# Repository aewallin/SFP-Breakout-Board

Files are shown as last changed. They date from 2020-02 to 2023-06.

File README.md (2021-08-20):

# SFP-Breakout-Board
SFP fibre-optical transciever simple breakout board. Works up to at least 1 Gbit/s.

* differential TX+/TX- RX+/RX- outputs/inputs with SMA connectors
* connector and cage for SFP or SFP+ transciever
* +3V3 power for transciever
* Three status LEDs for TX_FAULT, LOS, and MOD_ABS
* jumpers for SFP rate-select settings.

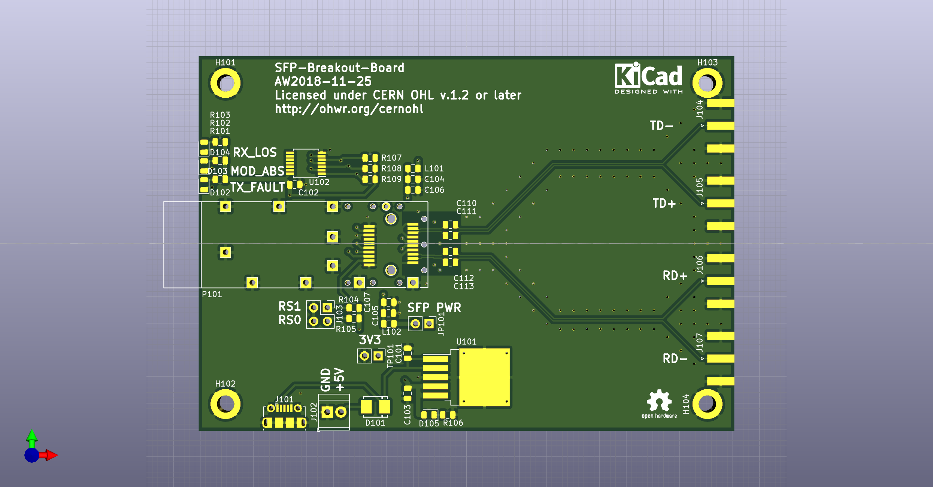
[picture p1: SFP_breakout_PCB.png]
PCB PCB image


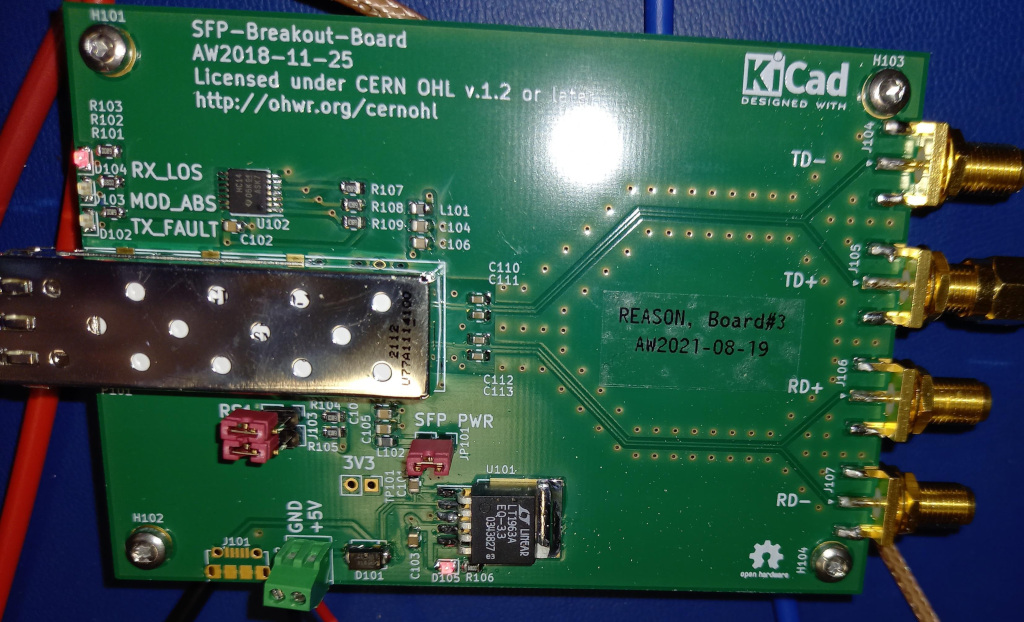
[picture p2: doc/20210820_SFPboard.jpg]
Board PCB image 2


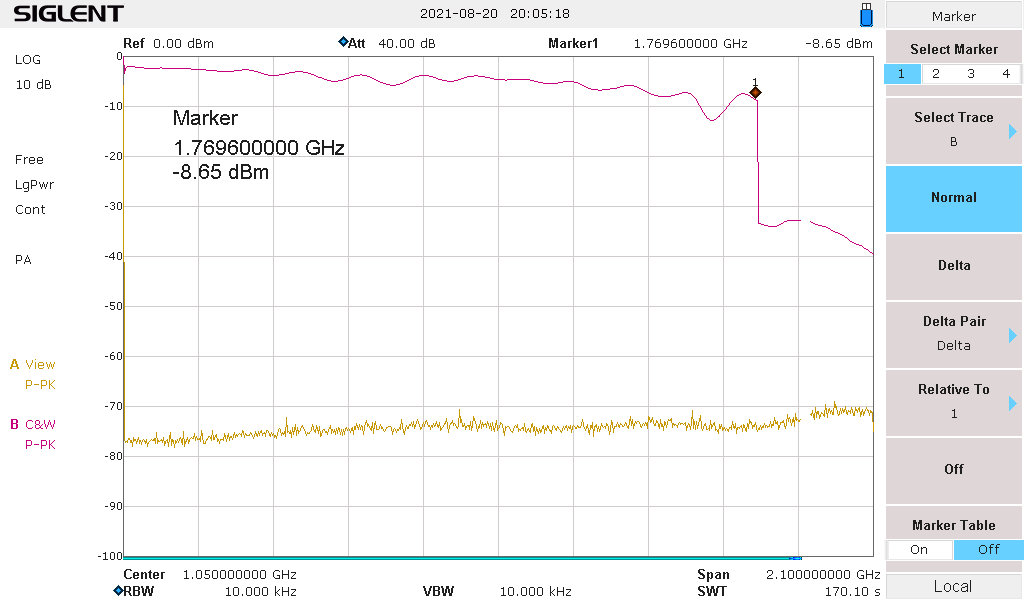
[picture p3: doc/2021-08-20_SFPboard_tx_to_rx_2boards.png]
SA Spectrum analyzer


Spectrum analyzer measurement of tracking-generator output to Tx-board with SFP, short 2 m fiber, and RX-output of receiving board with SFP. Bandwidth up to ca 1.8 GHz.

See also these other similar projects:

* https://github.com/aewallin/SFP2SMA_2018.03  single-ended input/output, with op-amp and transformer coupling to SFP
* https://osmocom.org/projects/misc-hardware/wiki/Sfp-experimenter
* https://osmocom.org/projects/misc-hardware/wiki/Sfp-breakout
* Multi-SFP crate https://www.ohwr.org/project/sfp-plus-i2c/wikis/home

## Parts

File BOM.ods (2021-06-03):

 | https://github.com/aewallin/SFP-Breakout-Board
 | Bill Of Materials
REF | Description | Qty | Price | Total | Farnell no | Digikey no | mfg part nr.
P101 | SFP connector | 1 |  |  | 1654067 | A97943CT-ND | 1888247-1
 | SFP Cage | 1 |  |  | 1849934 | U77-A1114-100TCT-ND | U77-A1114-100T
J104,105,106,107 | SMA connector | 4 | 5.25 |  |  | ACX1426-ND | 132289
U102 | 74HC14, TSSOP-14 | 1 |  |  |  | 296-8234-1-ND | SN74HC14PWR
D102, D103, D104 | SMD 0805 LED | 3
U101 | LT1963AEQ-3.3 | 1 |  |  |  | LT1963AEQ-3.3#TRPBFCT-ND | LT1963AEQ-3.3#TRPBF
J102 | 2-pin screw terminal | 1 |  |  |  | A98333-ND | 282834-2
L | SMD 0805 inductor
 | PCB, 2-sided, 90x70 mm | 10 | 12.5 | 125

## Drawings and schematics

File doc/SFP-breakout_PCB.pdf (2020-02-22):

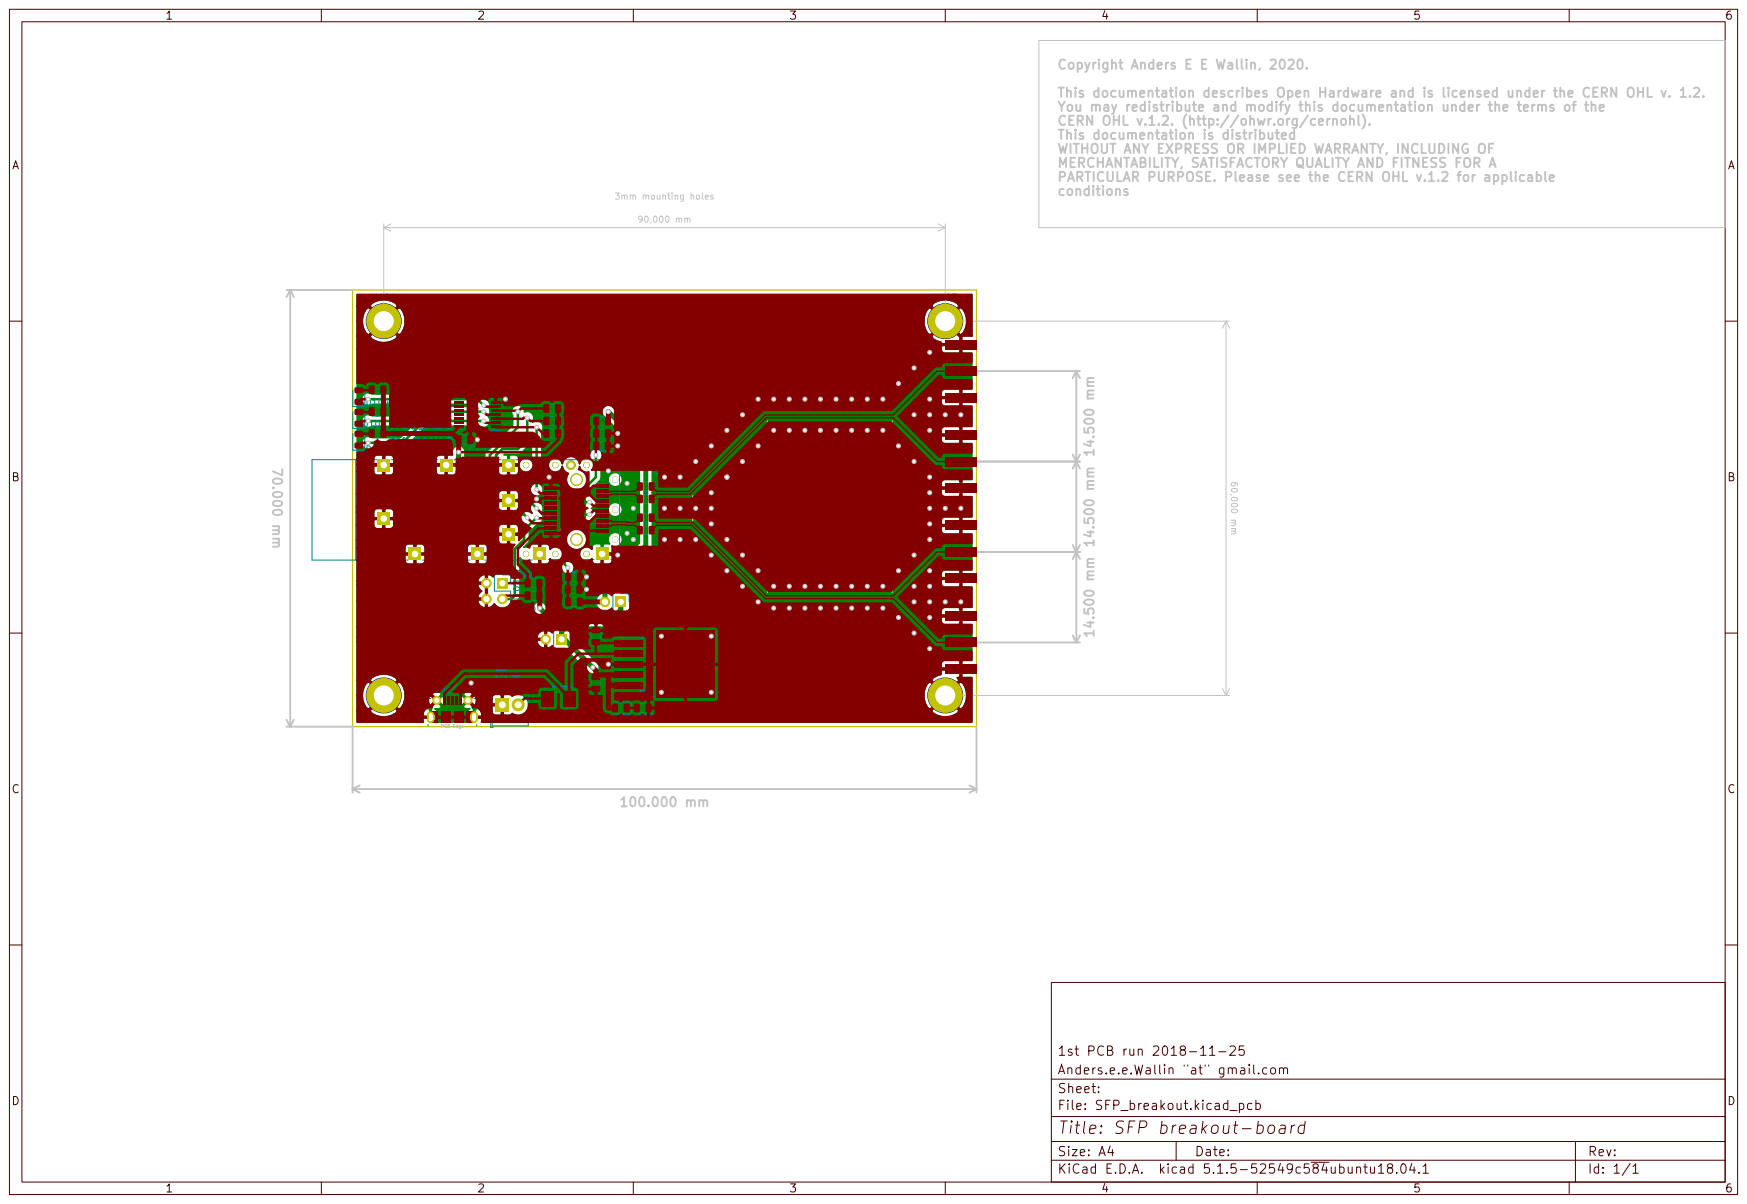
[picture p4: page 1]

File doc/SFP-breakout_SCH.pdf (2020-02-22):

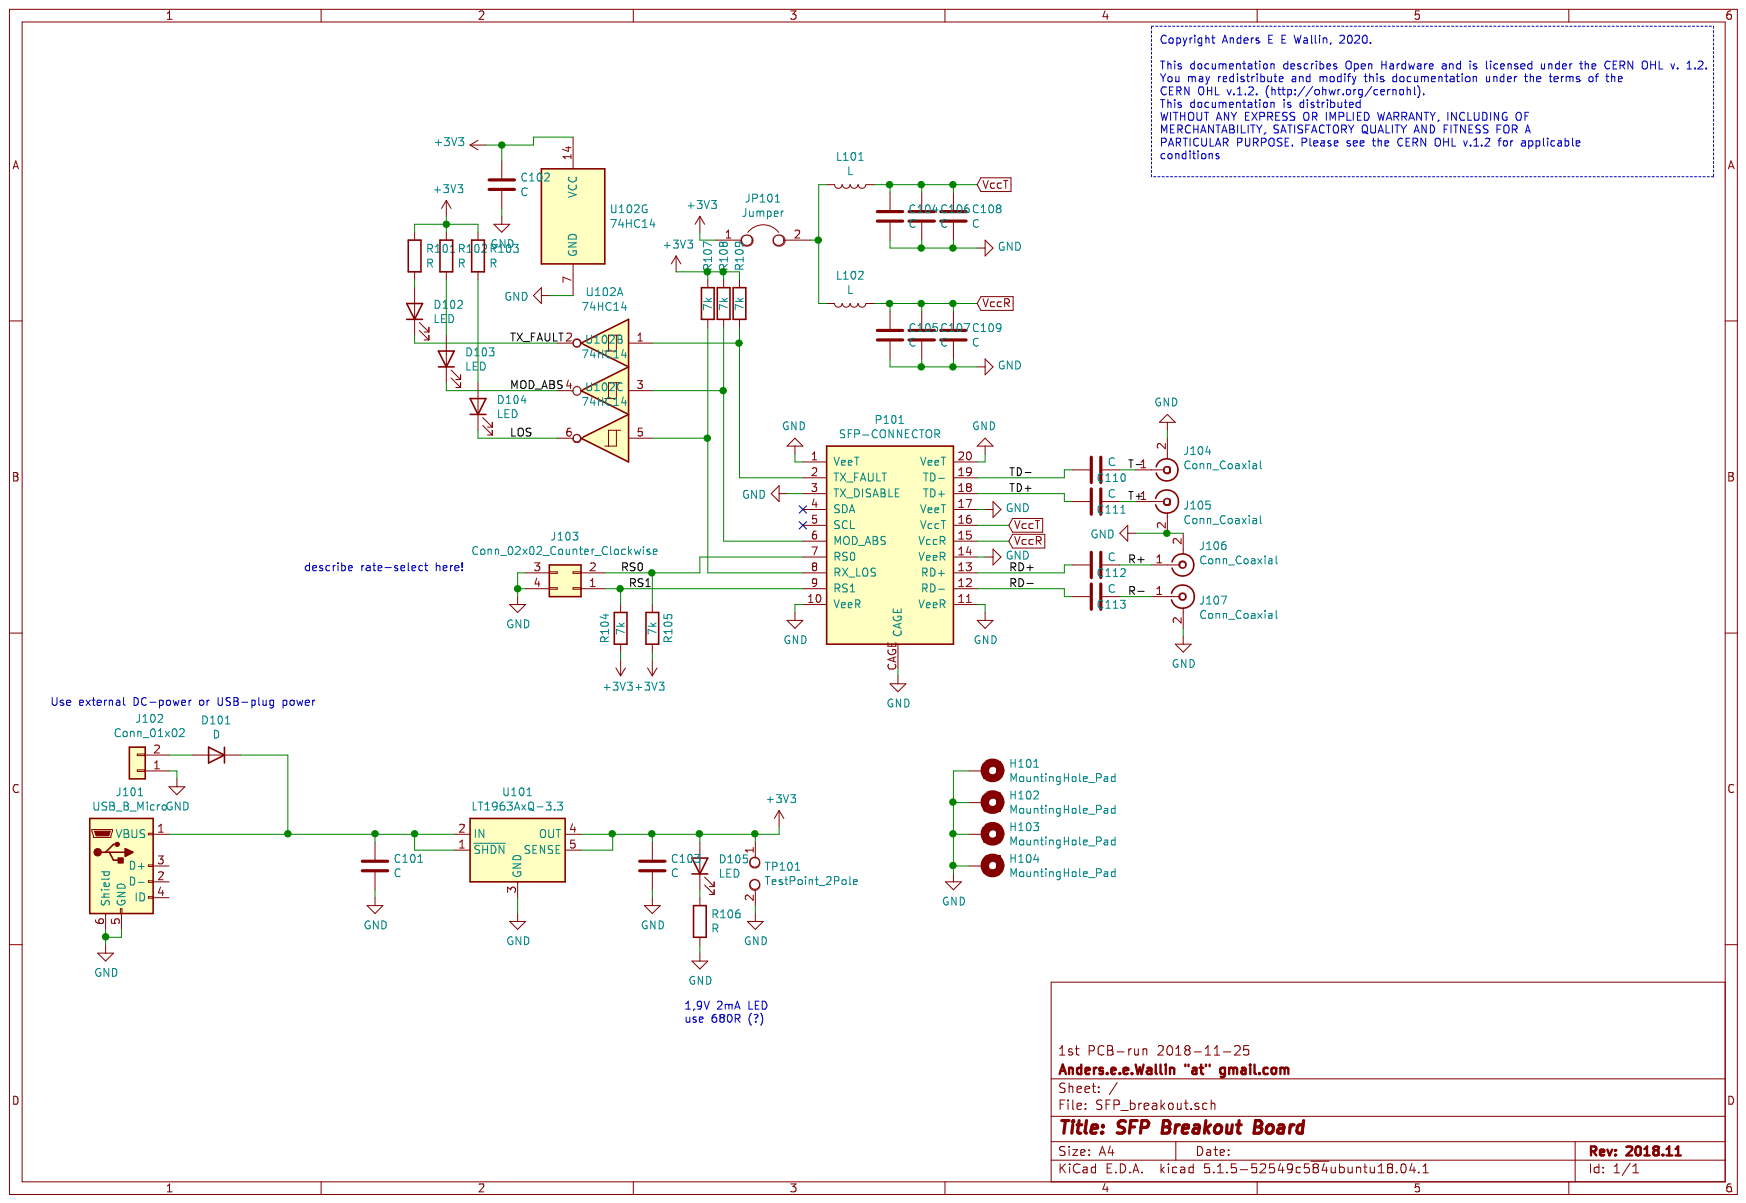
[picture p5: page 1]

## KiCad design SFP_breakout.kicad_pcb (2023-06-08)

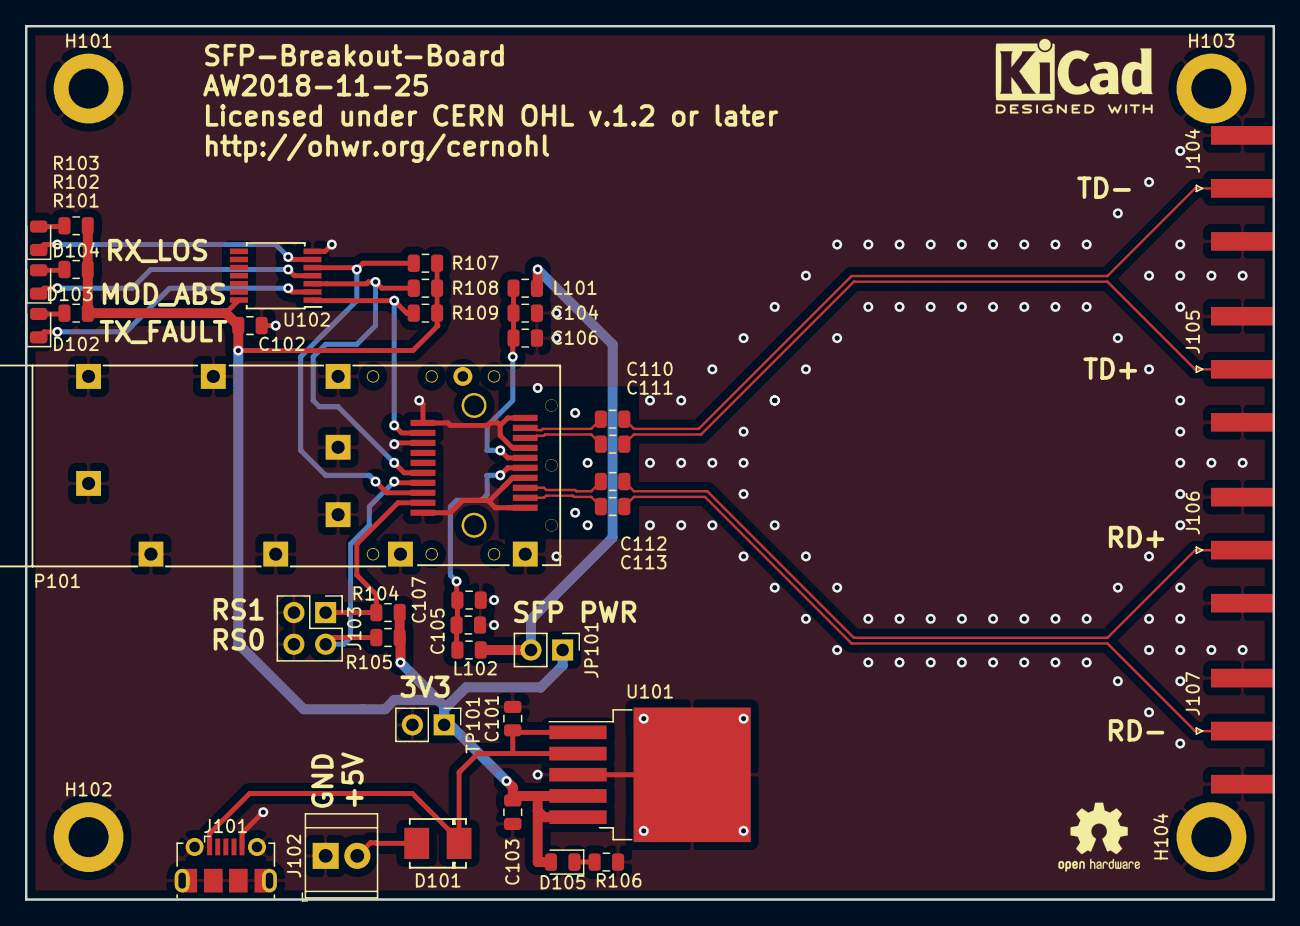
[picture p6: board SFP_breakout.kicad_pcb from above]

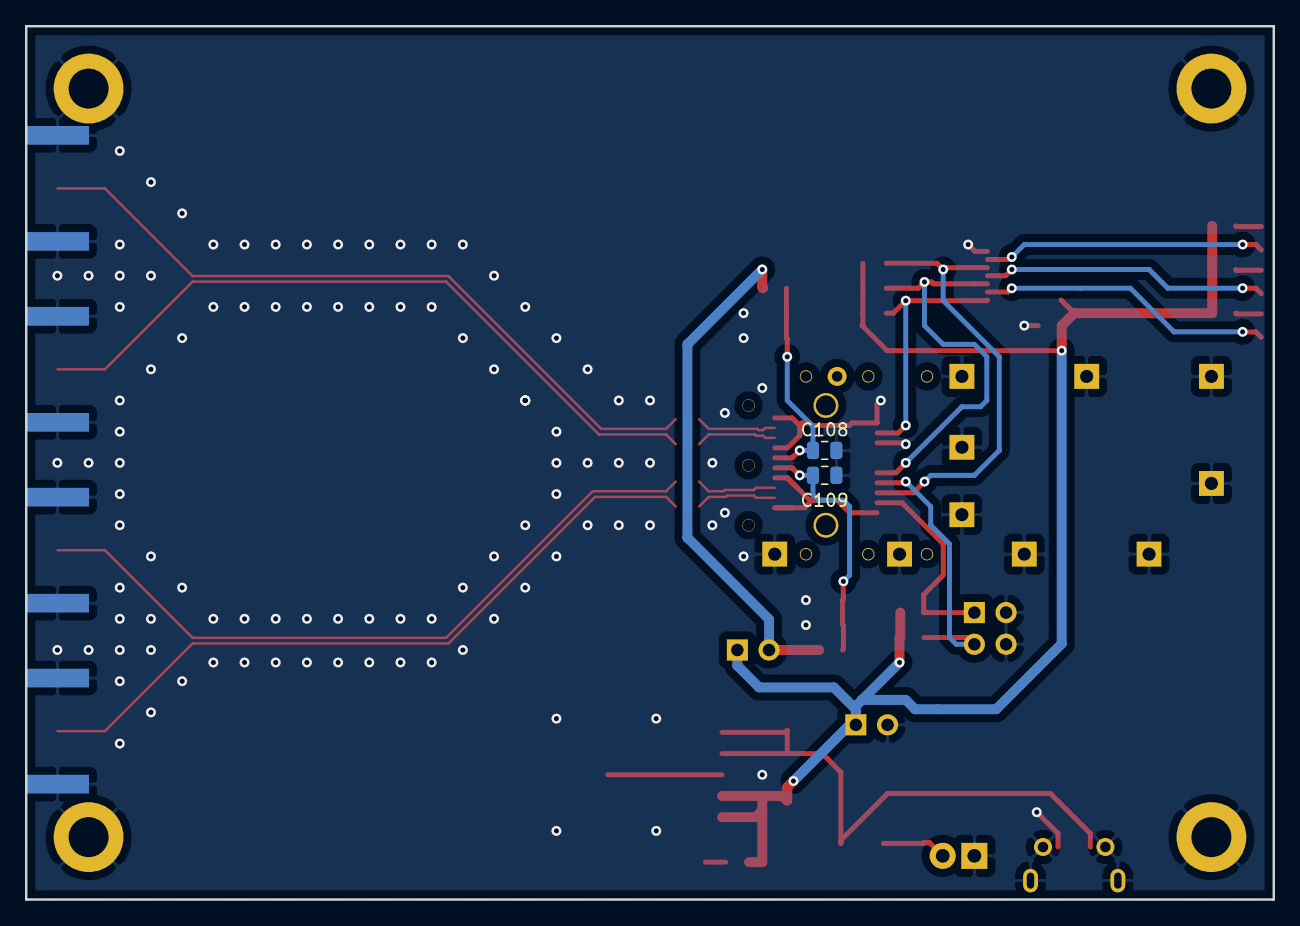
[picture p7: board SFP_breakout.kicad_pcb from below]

Board: 2 copper layers, 100.0 x 70.0 mm, 45 parts (2 on the bottom side), 27 nets.

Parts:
C101, C102, C103, C104, C105, C106, C107, C108, C109, C110, C111, C112, C113: C; C_0805_2012Metric
D101: D; DIODE_DO-214BA
D102, D103, D104, D105: LED; LED_0805_2012Metric
H101, H102, H103, H104: MountingHole_Pad; MountingHole_3.2mm_M3_DIN965_Pad
J101: USB_B_Micro; USB_Micro-B_Molex-105017-0001
J102: Conn_01x02; TerminalBlock_TE_282834-2_1x02_P2.54mm_Horizontal
J103: Conn_02x02_Counter_Clockwise; PinHeader_2x02_P2.54mm_Vertical
J104, J105, J106, J107: Conn_Coaxial; SMA_Amphenol_132289_EdgeMount
JP101: Jumper; PinHeader_1x02_P2.54mm_Vertical
L101, L102: L; L_0805_2012Metric
P101: SFP-CONNECTOR; Connector_SFP_and_Cage
R101, R102, R103, R106: R; R_0805_2012Metric
R104, R105, R107, R108, R109: 7k; R_0805_2012Metric
TP101: TestPoint_2Pole; PinHeader_1x02_P2.54mm_Vertical
U101: LT1963AxQ-3.3; TO-263-5_TabPin3
U102: 74HC14; TSSOP-14_4.4x5mm_P0.65mm

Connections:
+3V3: C102.1, C103.1, D105.2, JP101.1, R101.1, R102.1, R103.1, R104.2, R105.2, R107.1, R108.1, R109.1, TP101.1, U101.4, U101.5, U102.14
/LOS: D104.1, U102.6
/MOD_ABS: D103.1, U102.4
/R+: C112.1, J106.1
/R-: C113.1, J107.1
/RD+: C112.2, P101.13
/RD-: C113.2, P101.12
/RS0: J103.2, P101.7, R105.1
/RS1: J103.1, P101.9, R104.1
/T+: C111.1, J105.1
/T-: C110.1, J104.1
/TD+: C111.2, P101.18
/TD-: C110.2, P101.19
/TX_FAULT: D102.1, U102.2
GND: C101.2, C102.2, C103.2, C104.2, C105.2, C106.2, C107.2, C108.2, C109.2, H101.1, H102.1, H103.1, H104.1, J101.5, J101.6, J102.1, J103.3, J103.4, J104.2, J105.2, J106.2, J107.2, P101.1, P101.3, P101.10, P101.11, P101.14, P101.17, P101.20, P101.CAGE, R106.2, TP101.2, U101.3, U102.7
unnamed: C101.1, D101.1, J101.1, U101.1, U101.2
unnamed: D101.2, J102.2
unnamed: D102.2, R101.2
unnamed: D103.2, R102.2
unnamed: D104.2, R103.2
unnamed: D105.1, R106.1
unnamed: JP101.2, L101.2, L102.2
unnamed: P101.2, R109.2, U102.1
unnamed: P101.6, R108.2, U102.3
unnamed: P101.8, R107.2, U102.5
VccR: C105.1, C107.1, C109.1, L102.1, P101.15
VccT: C104.1, C106.1, C108.1, L101.1, P101.16

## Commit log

2020-02-22 add PCB image
2020-02-22 initial commit of files
    [SFP_breakout.kicad_pcb, SFP_breakout.sch]
2021-06-03 add BOM
    [BOM.ods]
2021-06-03 add documentation to schematic
    [SFP_breakout.sch]
2021-06-04 PCB order ca 2021-06-01
    [SFP_breakout.kicad_pcb]
2021-08-18 component values
    [SFP_breakout.sch]
2021-08-20 add notes
    [SFP_breakout.sch]
2023-06-08 kicad7 version
    [SFP_breakout.kicad_pcb, SFP_breakout.kicad_sch]
2023-06-08 remove old kicad files
    [SFP_breakout.sch]

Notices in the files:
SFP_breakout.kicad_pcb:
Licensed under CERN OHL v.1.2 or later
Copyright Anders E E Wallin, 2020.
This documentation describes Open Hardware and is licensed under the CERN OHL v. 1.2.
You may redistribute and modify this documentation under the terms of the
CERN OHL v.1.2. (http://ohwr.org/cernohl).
